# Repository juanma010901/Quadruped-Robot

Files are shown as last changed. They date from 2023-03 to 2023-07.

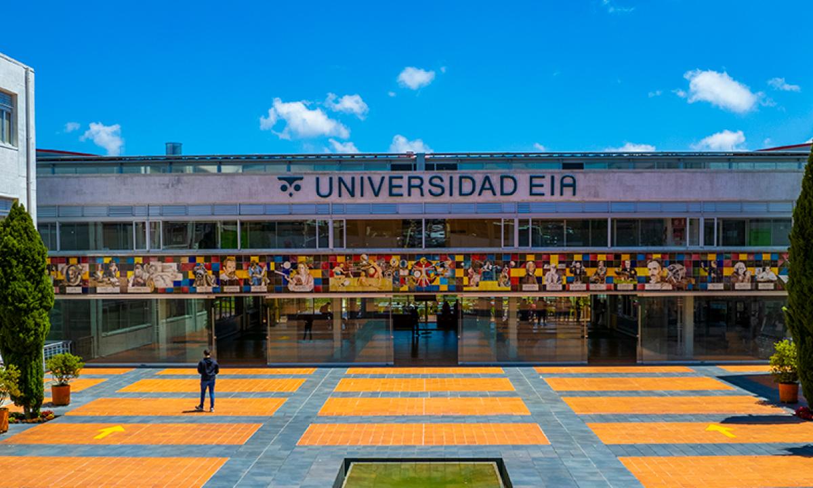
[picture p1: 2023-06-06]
Plataforma Web/FrontEnd/src/assets/UniversidadEIA_entrada.jpeg

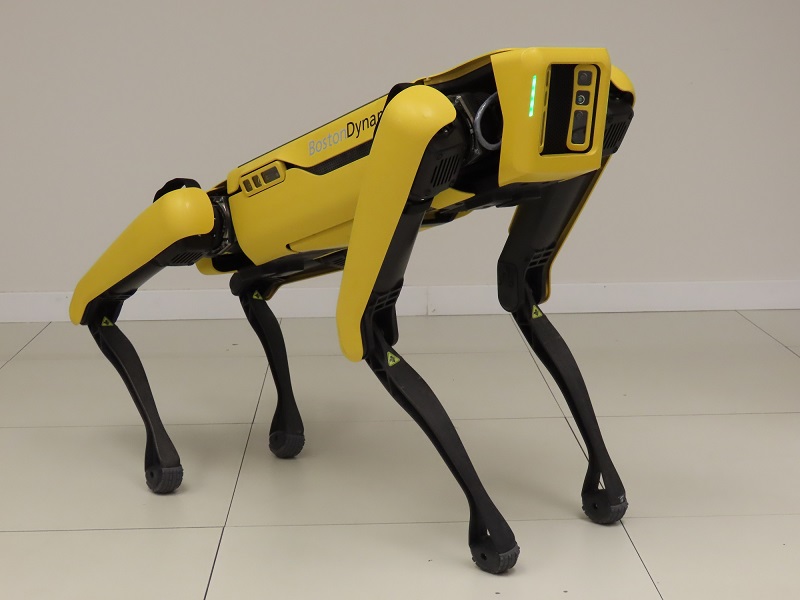
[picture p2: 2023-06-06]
Plataforma Web/FrontEnd/src/assets/robot_boston_dynamics.jpg

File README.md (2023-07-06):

<h1 align="center">
  <p>Diseño e implementación de un robot cuadrúpedo para la validación de estrategias de control en entornos peligrosos 🦾</p>
</h1>

<h2 align="center">
  <a href="https://juanma010901.github.io/Quadruped-Robot/">
    Quadruped Robot
  </a>
  <!--![Watchers](https://img.shields.io/github/watchers/juanma010901/Quadruped-Robot.svg)
  ![Stars](https://img.shields.io/github/stars/juanma010901/Quadruped-Robot.svg)-->
</h2><br>

<h3 align="center">
  <strong>Desarrollar un robot cuadrúpedo para el trabajo en entornos peligrosos como plataforma de validación de estrategias de control.</strong><br>
</h3>

<p align="center">
  Quadruped Robot
<p/>

A continuación se adjunta la [bitácora](https://docs.google.com/document/d/16br_ky9jK_mnqHfYBe1mgxbT8HZGymYTXOIlTPQXyck/edit?usp=sharing) del proyecto en la cual se podrán evidenciar las actividades realizadas durante cada fecha y los resultados obtenidos en la medida que se desarrollaba el proyecto.

## Materiales  🦾🔨
- [ESP32](https://github.com/juanma010901/Quadruped-Robot/blob/main/DataSheets/ESP32.pdf)
- [HC-SR04](https://github.com/juanma010901/Quadruped-Robot/blob/main/DataSheets/HC-SR04.PDF) x 2
- [LM2596](https://github.com/juanma010901/Quadruped-Robot/blob/main/DataSheets/LM2596.pdf) x2
- [MG996R](https://github.com/juanma010901/Quadruped-Robot/blob/main/DataSheets/MG996R.pdf) x 8
- [PCA9685](https://github.com/juanma010901/Quadruped-Robot/blob/main/DataSheets/PCA9685.PDF)
- [LCD16x2](https://github.com/juanma010901/Quadruped-Robot/blob/main/DataSheets/LCD16x2.pdf)
- [I2C Module](https://github.com/juanma010901/Quadruped-Robot/blob/main/DataSheets/I2C-1602-LCD.pdf)
<!-- - [Arduino Nano]()  -->

## Contributors 💡 and Contact 📩
| Juan Manuel Hincapié | Luis Alejandro Pépez | David Rozo Osorio | Universidad EIA |
| :---: | :---: | :---: | :---: |
| <a href="https://github.com/juanma010901">Juan Manuel</a> |  <a href="https://github.com/luisfbcudj94">Luis Pérez</a> |<a href="david.rozo31@eia.edu.co">David Rozo</a>| <a href="https://www.linkedin.com/school/universidad-eia/?originalSubdomain=co">Universidad EIA</a>| 
|  |  |  |

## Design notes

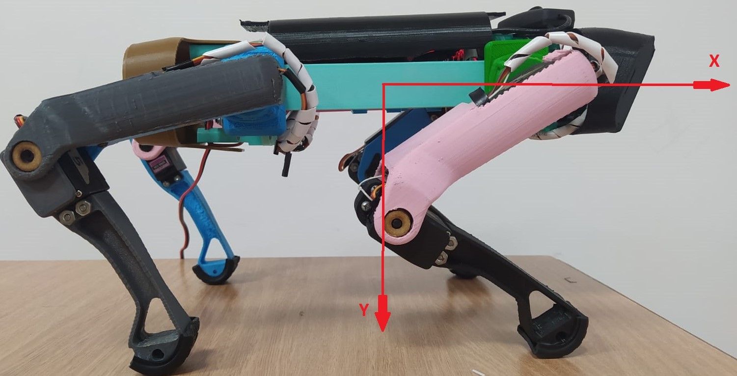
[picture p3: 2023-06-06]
Plataforma Web/FrontEnd/src/assets/EJES_ROBOT.jpeg

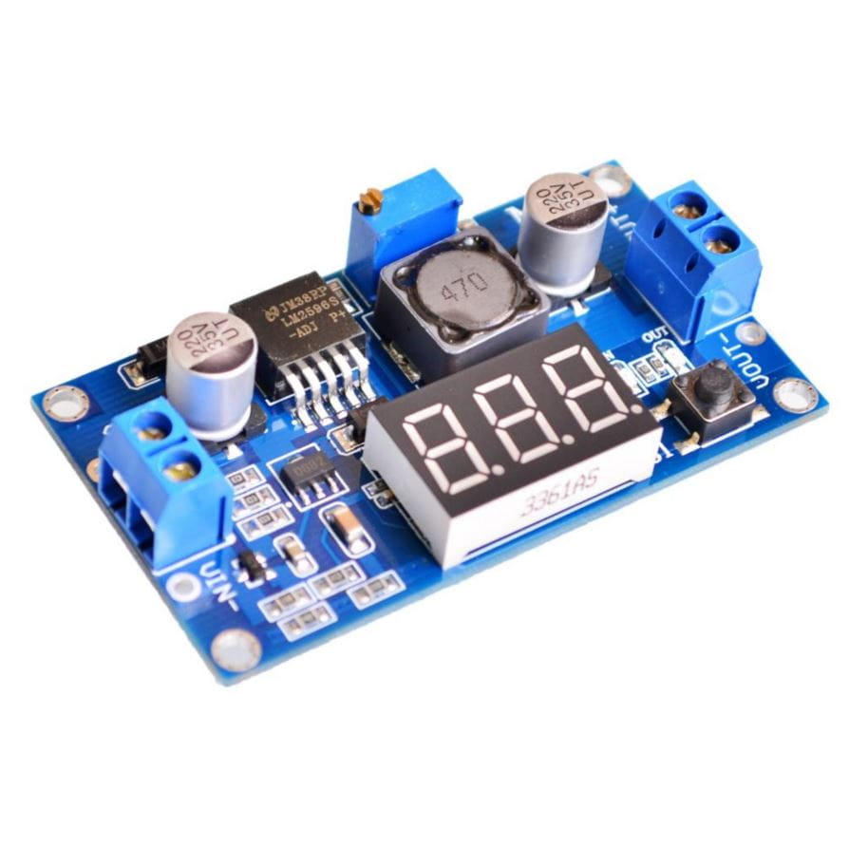
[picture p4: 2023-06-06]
DataSheets/LM2596-LED.jpg

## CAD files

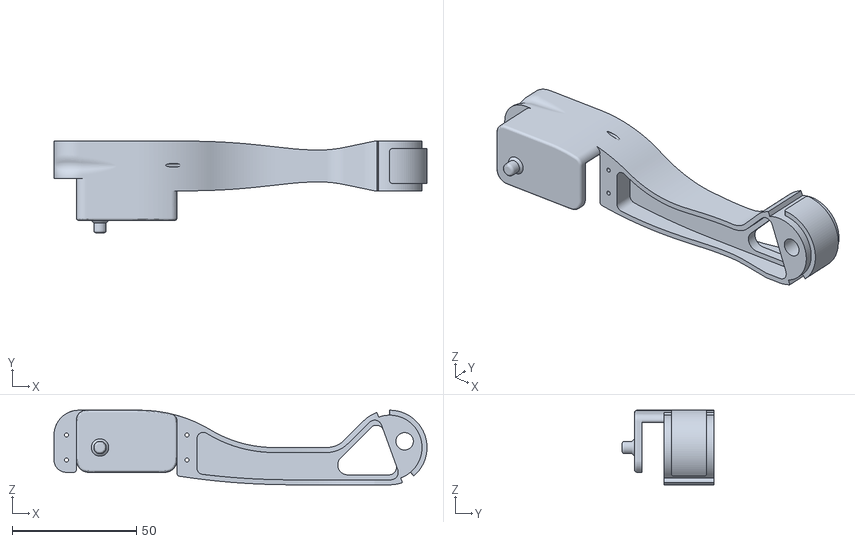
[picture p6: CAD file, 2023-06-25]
Diseños/files/V1.01_Left_Wrist.stl
150.0 x 36.9 x 30.0

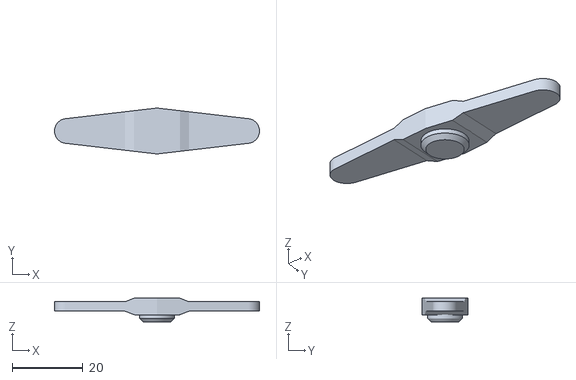
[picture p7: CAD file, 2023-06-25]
Diseños/files/ServoHorn_.stl
58.0 x 13.0 x 6.70

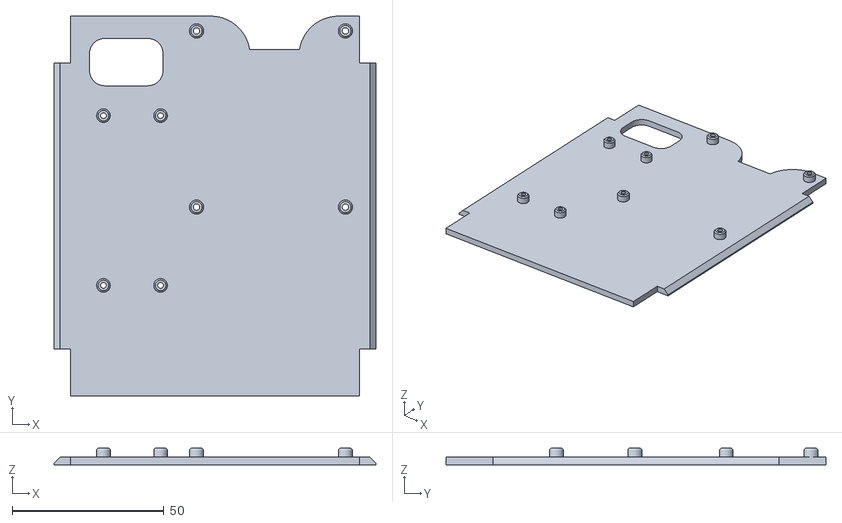
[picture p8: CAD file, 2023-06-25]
Diseños/files/V1.00_Chassis_PlateRPi.stl
106.0 x 125.0 x 5.44

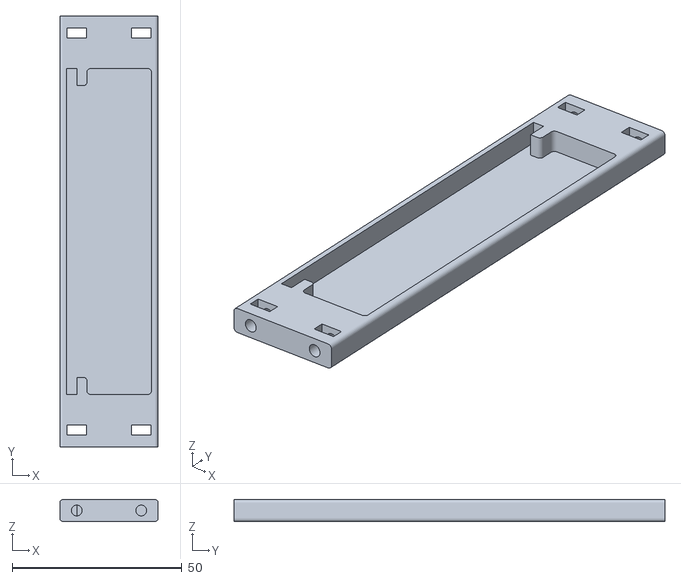
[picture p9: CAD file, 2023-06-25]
Diseños/files/V1.00_Chassis_Right.stl
29.0 x 127.0 x 6.50

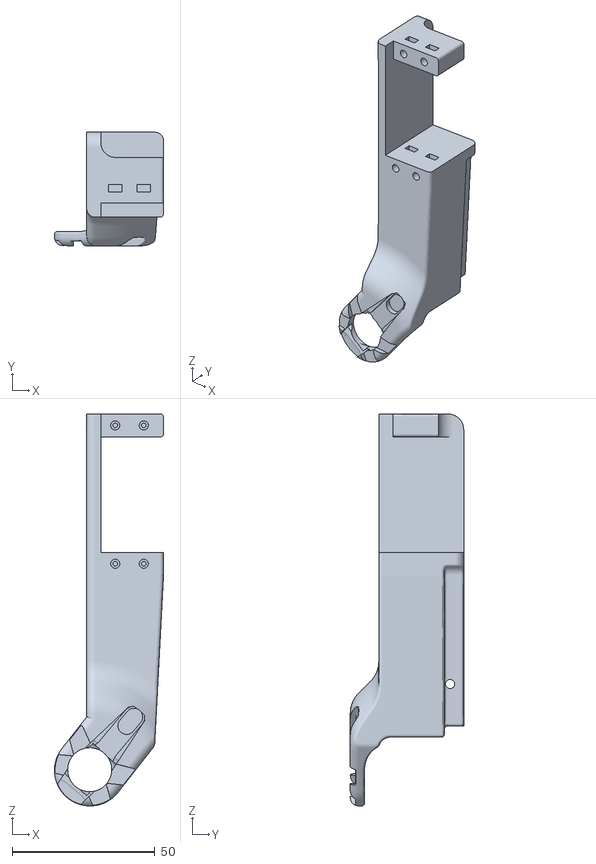
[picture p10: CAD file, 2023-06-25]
Diseños/files/V1.01_Right_MidArm.stl
38.3 x 39.8 x 137.4

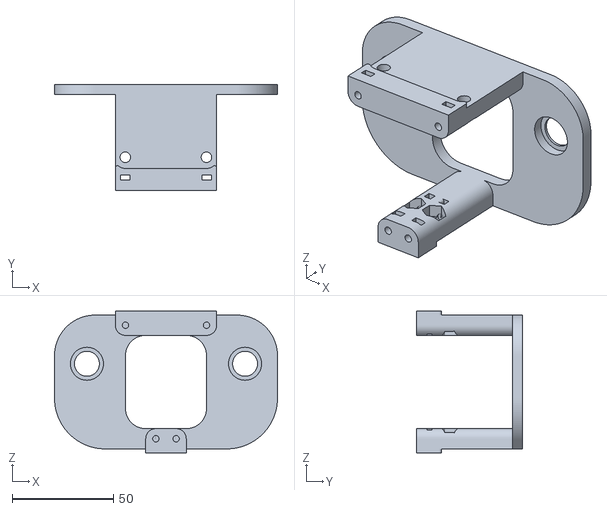
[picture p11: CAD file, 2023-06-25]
Diseños/files/V1.01_Rear_Shoulder_Outer.stl
110.0 x 52.5 x 70.0

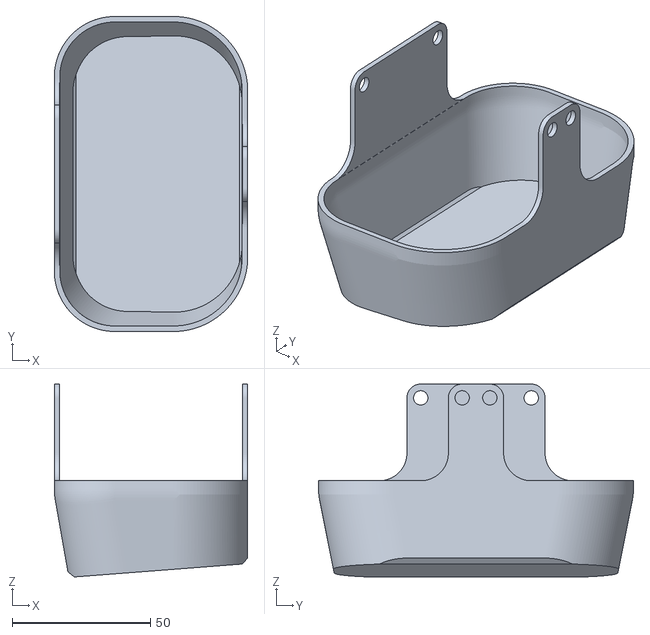
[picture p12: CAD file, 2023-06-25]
Diseños/files/V1.00_Body_Cover_Rearblank.stl
70.0 x 114.0 x 69.8

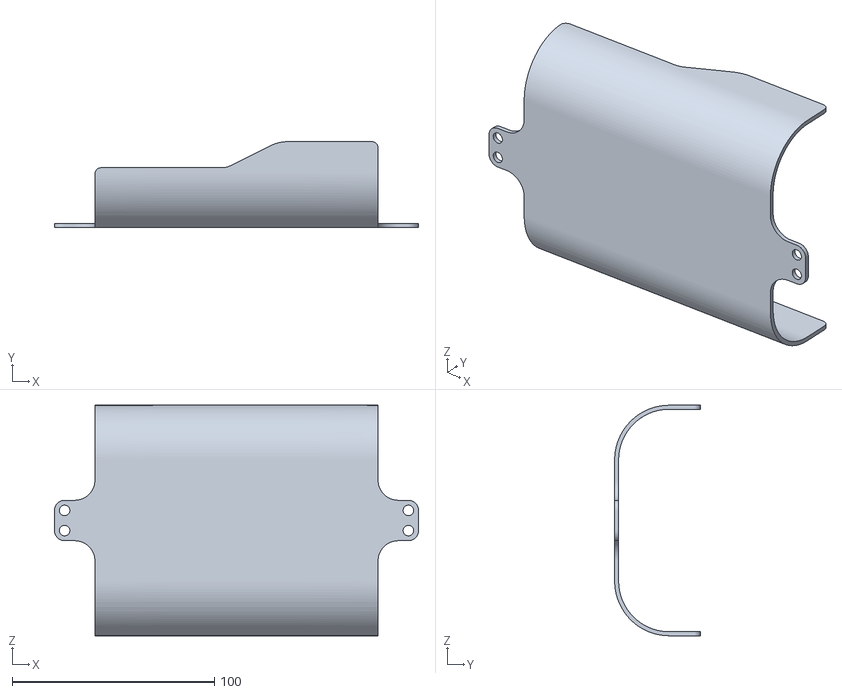
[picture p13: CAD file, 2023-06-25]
Diseños/files/V1.00_Body_Cover_Bottom.stl
180.0 x 42.4 x 114.0

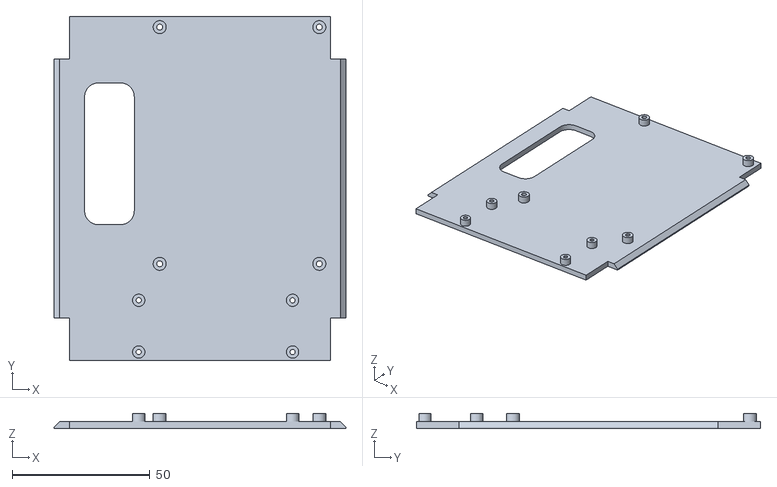
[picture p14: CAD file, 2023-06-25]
Diseños/files/V1.00_Chassis_PlateJetsonNano.stl
106.0 x 125.0 x 5.50

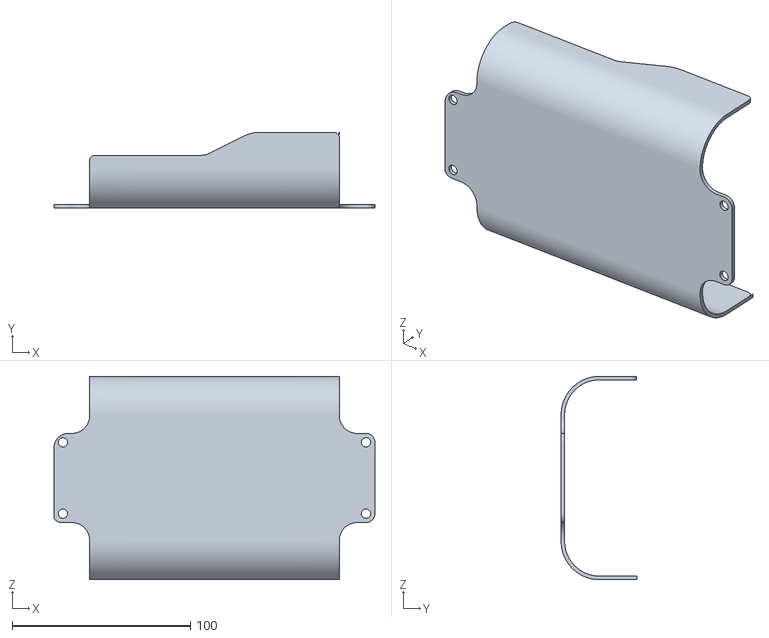
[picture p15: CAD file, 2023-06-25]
Diseños/files/V1.00_Body_Cover_Top.stl
180.0 x 42.5 x 114.0

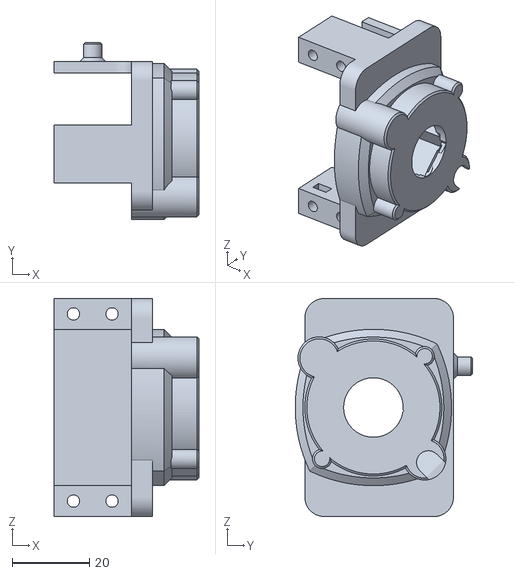
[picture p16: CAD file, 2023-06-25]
Diseños/files/V1.01_Left_UpperArm.stl
37.5 x 46.0 x 56.5

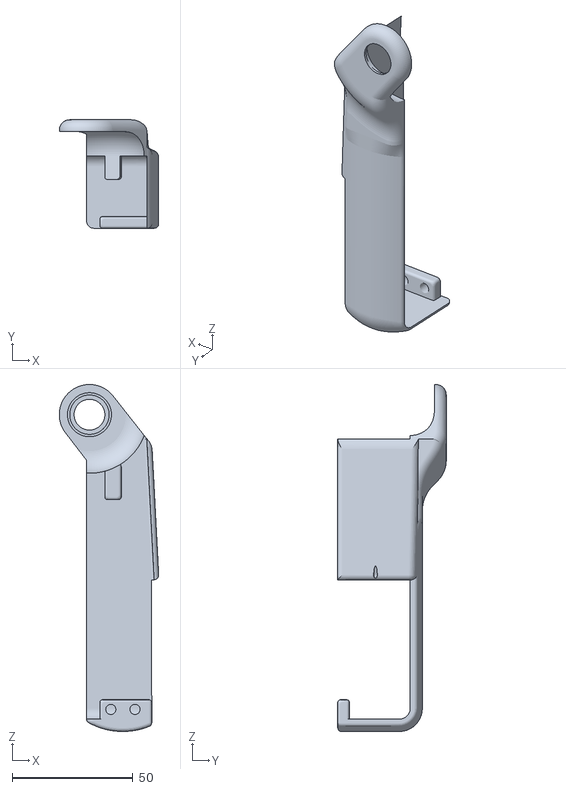
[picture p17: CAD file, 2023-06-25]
Diseños/files/V1.01_Left_MidArm_Cover.stl
41.1 x 44.9 x 143.6

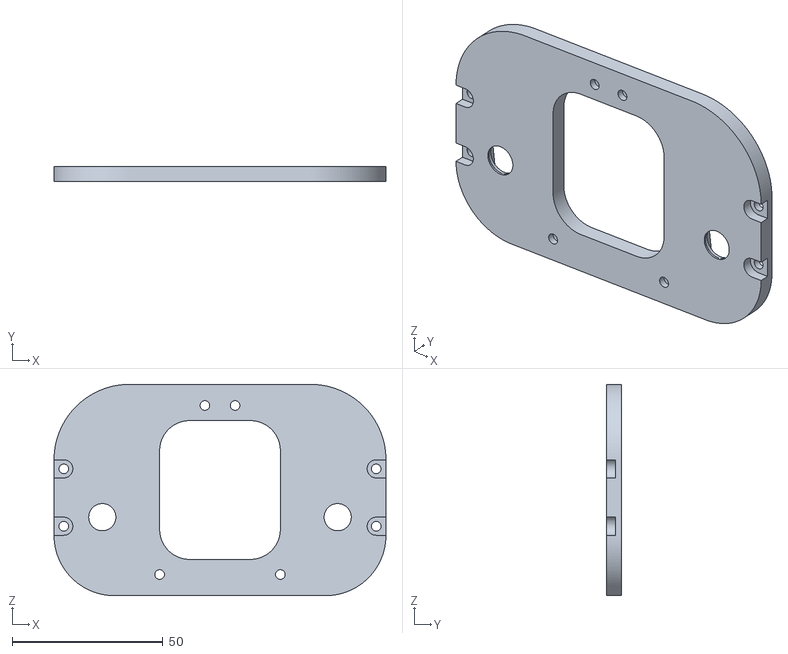
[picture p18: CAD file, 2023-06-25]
Diseños/files/V1.01_Rear_Shoulder_Inner.stl
110.0 x 5.00 x 70.0

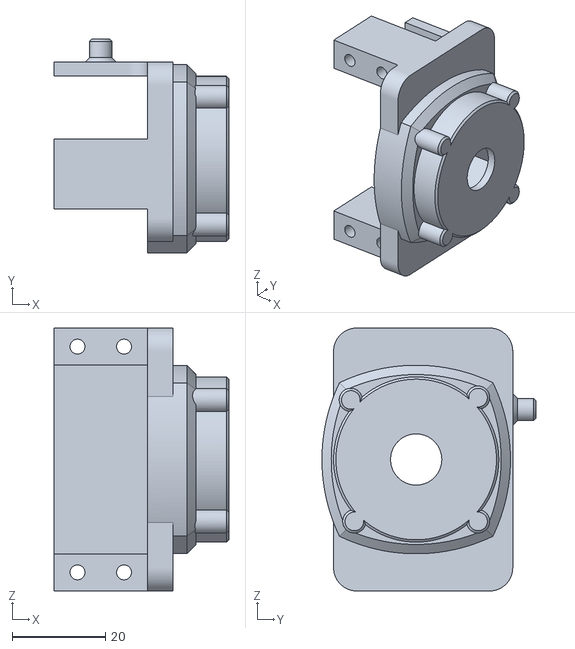
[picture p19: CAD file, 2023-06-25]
Diseños/files/UpperArm.stl
37.5 x 46.0 x 56.5

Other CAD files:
Diseños/files/WristForearm.stl
Diseños/files/V1.01_Right_Wrist.stl
Diseños/files/MidArm.stl
Diseños/files/V1.01_Right_MidArm_Cover.stl
Diseños/files/F_cover.stl
Diseños/files/Midarm_Cover.stl
Diseños/files/Outer_Shoulder.stl
Diseños/files/Rear_Cover.stl
Diseños/files/V1.00_Chassis_Left.stl
Diseños/files/V1.00_Foot.stl
Diseños/files/V1.00_Nose.stl
Diseños/files/V1.01_Front_Shoulder_Inner.stl
Diseños/files/V1.01_Front_Shoulder_Outer.stl
Diseños/files/V1.01_Left_MidArm.stl
Diseños/files/V1.01_Right_UpperArm.stl

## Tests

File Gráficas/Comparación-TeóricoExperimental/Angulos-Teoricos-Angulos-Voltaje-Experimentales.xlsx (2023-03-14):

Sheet: Hoja1
Voltaje M1 | Voltaje M2 | Puntos | Grados Teoricos M1 | Grados Teoriocos M2 | Grados linealizados M1 | Grados Linealizados M2
2.62066 | 0.851801 | 1 | 145.827 | 105.151 | 151.398 | 111.297
2.47645 | 0.37469 | 2 | 136.596 | 134.488 | 141.395 | 144.391
2.02189 | 1.06536 | 3 | 108.335 | 91.0852 | 109.865 | 96.484
2.61744 | 0.906587 | 4 | 145.827 | 105.151 | 151.175 | 107.497

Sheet: Hoja2
PUNTO | X | Y | VOLTAJE M1 | VOLTAJE M2 | PUNTO | GRADOS TEORICOS M1 | GRADOS TEORICOS M2 | GRADOS LINEALIZADOS M1 | GRADOS LINEALIZADOS M2 | GRADOS LINEALIZADOS CON AJUSTE M1 | GRADOS LINEALIZADOS CON AJUSTE M2 | DIFERENCIA TEORICOS - LINEALIZADOS | DIFERENCIA TEORICO - LINEALIZADOS AJUSTADOS
1 |  |  | 2.06218 | 1.38929 | 1 | 112.143 | 64.8972 | 112.66 | 69.0148 | 107.66 | 64.0148 | 0.461018521 | 3.997574525
2 |  |  | 2.82777 | 1.49246 | 2 | 157.909 | 59.2453 | 165.764 | 61.858 | 160.764 | 56.858 | 4.974383981 | 1.808003344
3 |  |  | 2.45061 | 0.985543 | 3 | 134.858 | 91.7365 | 139.603 | 97.0201 | 134.603 | 92.0201 | 3.518515772 | 0.1890877812
4 |  |  | 2.73592 | 1.37317 | 4 | 152.814 | 66.5638 | 159.393 | 70.1324 | 154.393 | 65.1324 | 4.305233814 | 1.033282291
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

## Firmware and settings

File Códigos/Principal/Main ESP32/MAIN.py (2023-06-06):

#print("Hello World!")
import adafruit_hcsr04
import adafruit_pca9685
import adafruit_minimqtt.adafruit_minimqtt as MQTT
import adafruit_requests as requests
import analogio
import board
import busio
import digitalio
import ipaddress
import json
import math
import pulseio
import wifi_networks
import socketpool
import ssl
import time
import wifi
from adafruit_motor import servo

#---------------------------------------------------------------------------------

#EndPoints API
getPuntos = "https://tg-backend-jl.azurewebsites.net/api/GetPuntos"
getModo = "https://tg-backend-jl.azurewebsites.net/api/GetModoActual"
updateModo = "https://tg-backend-jl.azurewebsites.net/api/ActualizarModo"

#getPuntos = "https://masterusers.azurewebsites.net/api/GetPuntos"
#getModo = "https://masterusers.azurewebsites.net/api/GetModoActual"
#updateModo = "https://masterusers.azurewebsites.net/api/ActualizarModo"


def connection():
    print("INICIO")
    wifi_networks.connect()
    print("FIN")
connection()

pool = socketpool.SocketPool(wifi.radio)
https = requests.Session(pool, ssl.create_default_context())

#---------------------------------------------------------------------------------

# Configura los LEDs
ledHome = digitalio.DigitalInOut(board.D5)
ledHome.direction = digitalio.Direction.OUTPUT
ledMarchas = digitalio.DigitalInOut(board.D18)
ledMarchas.direction = digitalio.Direction.OUTPUT
ledManiobras = digitalio.DigitalInOut(board.D19)
ledManiobras.direction = digitalio.Direction.OUTPUT
ledManual = digitalio.DigitalInOut(board.D23)
ledManual.direction = digitalio.Direction.OUTPUT

#--------------------------------------------------------------------------------
#Configuración de los ultrasonidos

# Configurar los pines Trig y Echo del sensor de ultrasonido
echo_pin1 = board.D34
echo_pin2 = board.D35
trig_pin1 = board.D32
trig_pin2 = board.D33

# Configurar el temporizador para medir la duración del pulso de eco
timer1 = pulseio.PulseIn(echo_pin1, maxlen=1)
timer2 = pulseio.PulseIn(echo_pin2, maxlen=1)

# Configurar el objeto del sensor de ultrasonido
sonar1 = adafruit_hcsr04.HCSR04(trigger_pin=trig_pin1, echo_pin=echo_pin1, timeout=0.1)
sonar2 = adafruit_hcsr04.HCSR04(trigger_pin=trig_pin2, echo_pin=echo_pin2, timeout=0.1)

#---------------------------------------------------------------------------------

#Suma
def puntosP1():
    x = [6, 9, 3]
    y = [11, 12, 13]
    return ([x, y])

def puntosP2():
    x = [0, 3, -3]
    y = [12, 14, 14]
    return ([x, y])

#Resta
def puntosP3():
    x = [0, -3, 3]
    y = [12, 14, 14]
    return ([x, y])

def puntosP4():
    x = [-3, -6, 0]
    y = [11, 12, 13]
    return ([x, y])

def puntosHome():
    puntosP1 = [3, 13]
    puntosP2 = [-3, 14]
    puntosP3 = [3, 14]
    puntosP4 = [0, 13]
    return([puntosP1, puntosP2, puntosP3, puntosP4])

def puntosAgachado():
    puntosP1 = [2, 9]
    puntosP2 = [-1, 9]
    puntosP3 = [1, 9]
    puntosP4 = [-1, 9]
    return([puntosP1, puntosP2, puntosP3, puntosP4])
    
def puntosParado():
    puntosP1 = [4, 20]
    puntosP2 = [-5, 21]
    puntosP3 = [5, 21]
    puntosP4 = [0, 20]
    return([puntosP1, puntosP2, puntosP3, puntosP4])

def puntosAdelante():
    puntosP1 = [6, 10]
    puntosP2 = [-1, 19]
    puntosP3 = [1, 19]
    puntosP4 = [-4, 10]
    return([puntosP1, puntosP2, puntosP3, puntosP4])

def puntosAtras():
    puntosP1 = [2, 17]
    puntosP2 = [-4, 11]
    puntosP3 = [4, 11]
    puntosP4 = [1, 17]
    return([puntosP1, puntosP2, puntosP3, puntosP4])

def puntosIzquierda():
    puntosP1 = [3, 11]
    puntosP2 = [-4, 11]
    puntosP3 = [4, 19]
    puntosP4 = [1, 19]
    return([puntosP1, puntosP2, puntosP3, puntosP4])

def puntosDerecha():
    puntosP1 = [3, 20]
    puntosP2 = [-3, 20]
    puntosP3 = [4, 12]
    puntosP4 = [-1, 12]
    return([puntosP1, puntosP2, puntosP3, puntosP4])

#---------------------------------------------------------------------------------

# Definición de pines I2C
SDA = board.D21
SCL = board.D22

# Configuración del bus I2C
i2c = busio.I2C(SCL, SDA)
pca = adafruit_pca9685.PCA9685(i2c, address=0x40)
pca.frequency = 50

# Configuración del Servomotor
servo_1 = servo.Servo(pca.channels[0], min_pulse=500, max_pulse=2500)
servo_2 = servo.Servo(pca.channels[2], min_pulse=500, max_pulse=2500)
servo_3 = servo.Servo(pca.channels[4], min_pulse=500, max_pulse=2500)
servo_4 = servo.Servo(pca.channels[6], min_pulse=500, max_pulse=2500)
servo_5 = servo.Servo(pca.channels[8], min_pulse=500, max_pulse=2500)
servo_6 = servo.Servo(pca.channels[10], min_pulse=500, max_pulse=2500)
servo_7 = servo.Servo(pca.channels[12], min_pulse=500, max_pulse=2500)
servo_8 = servo.Servo(pca.channels[14], min_pulse=500, max_pulse=2500)

# Definir las longitudes de las dos articulaciones del robot
l1 = 11
l2 = 13

#---------------------------------------------------------------------------------

# Funcion inversa izquierda
def inversaIzquierda(x, y):
    #print("Punto:" + str(x[i]) + "," + str(y[i]))
    #Calcular el valor de theta 2
    theta2 = math.acos((x**2 + y**2 - l1**2 - l2**2) / (2*l1*l2))

    # Calcular el valor de theta 1
    theta1 = math.atan2(y, x) + math.atan2(l2*math.sin(theta2), l1+l2*math.cos(theta2))
    
    #Angulos corregidos
    theta1c = math.degrees(theta1) - 90
    theta2c = 140 - math.degrees(theta2)

    return([theta1c,theta2c])

# Funcion inversa derecha
def inversaDerecha(x, y):
    #print("Punto:" + str(x[i]) + "," + str(y[i]))
    #Calcular el valor de theta 2
    theta2 = math.acos((x**2 + y**2 - l1**2 - l2**2) / (2*l1*l2))

    # Calcular el valor de theta 1
    theta1 = math.atan2(y, x) - math.atan2(l2*math.sin(theta2), l1+l2*math.cos(theta2))
    
    #Angulos corregidos
    theta1c = math.degrees(theta1)
    theta2c = math.degrees(theta2) + 40

    return([theta1c,theta2c])

#---------------------------------------------------------------------------------

# Mover Pata 1 (izquierda)
def calcularAngulosP1():
    
    # Invocar los puntos para mover las patas izquierdas
    puntos = puntosP1()
    x = puntos[0]
    y = puntos[1]

    angulosP1 = []

    for i in range(len(x)):
        angulosP1.append(inversaIzquierda(x[i],y[i]))
    return angulosP1

# Mover Pata 2 (izquierda)
def calcularAngulosP2():
    #Definir los vectores x e y
    puntos = puntosP2()
    x = puntos[0]
    y = puntos[1]

    angulosP2 = []

    for i in range(len(x)):
        angulosP2.append(inversaIzquierda(x[i],y[i]))
    return angulosP2
    
# Mover Pata 3 (derecha)
def calcularAngulosP3():
    #Definir los vectores x e y
    puntos = puntosP3()
    x = puntos[0]
    y = puntos[1]

    angulosP3 = []

    for i in range(len(x)):
        angulosP3.append(inversaDerecha(x[i],y[i]))
    return angulosP3

# Mover Pata 4 (derecha)
def calcularAngulosP4():
    puntos = puntosP4()
    x = puntos[0]
    y = puntos[1]

    angulosP4 = []

    for i in range(len(x)):
        angulosP4.append(inversaDerecha(x[i],y[i]))
    return angulosP4

#---------------------------------------------------------------------------------

#Funciones para mover las patas e imprimir la información
def moverP1(puntosP1):
    for i in range(len(puntosP1)):
            servo_1.angle = puntosP1[i][0]
            servo_2.angle = puntosP1[i][1]
            time.sleep(0.6)
            
def moverP2(puntosP2):
    for i in range(len(puntosP2)):
            servo_3.angle = puntosP2[i][0]
            servo_4.angle = puntosP2[i][1]
            time.sleep(0.6)
            
def moverP3(puntosP3):
    for i in range(len(puntosP3)):
            servo_5.angle = puntosP3[i][0]
            servo_6.angle = puntosP3[i][1]
            time.sleep(0.6)
            
def moverP4(puntosP4):
    for i in range(len(puntosP4)):
            servo_7.angle = puntosP4[i][0]
            servo_8.angle = puntosP4[i][1]
            time.sleep(0.6)

#---------------------------------------------------------------------------------
            
def moverP1P3(puntosP1, puntosP3):
    for i in range(len(puntosP1)):             
        servo_1.angle = puntosP1[i][0]
        servo_2.angle = puntosP1[i][1]
        servo_5.angle = puntosP3[i][0]
        servo_6.angle = puntosP3[i][1]
        time.sleep(0.3)
            
def moverP2P4(puntosP2, puntosP4):
    for i in range(len(puntosP2)):
            servo_3.angle = puntosP2[i][0]
            servo_4.angle = puntosP2[i][1]
            servo_7.angle = puntosP4[i][0]
            servo_8.angle = puntosP4[i][1]
            time.sleep(0.3)
      
#--------------------------------------------------------------------------------- 
            
def pararse():
    home = puntosHome()
    servo_3.angle, servo_4.angle = inversaIzquierda(home[1][0], home[1][1])
    servo_5.angle, servo_6.angle = inversaDerecha(home[2][0], home[2][1])
    time.sleep(0.3)
    servo_1.angle, servo_2.angle = inversaIzquierda(home[0][0], home[0][1])
    servo_7.angle, servo_8.angle = inversaDerecha(home[3][0], home[3][1])
    #time.sleep(0.1)
      
#--------------------------------------------------------------------------------- 
            
def home():
    home = puntosHome()
    servo_3.angle, servo_4.angle = inversaIzquierda(home[1][0], home[1][1])
    servo_5.angle, servo_6.angle = inversaDerecha(home[2][0], home[2][1])
    servo_1.angle, servo_2.angle = inversaIzquierda(home[0][0], home[0][1])
    servo_7.angle, servo_8.angle = inversaDerecha(home[3][0], home[3][1])
    #time.sleep(0.1)


#---------------------------------------------------------------------------------
            
#Marcha sencilla en la que se mueve un paso a la vez        
def marchaSencilla():
    moverP1(calcularAngulosP1())
    time.sleep(0.1)
    moverP3(calcularAngulosP3())
    time.sleep(0.1)
    moverP4(calcularAngulosP4())
    time.sleep(0.1)
    moverP2(calcularAngulosP2())
    time.sleep(0.1)

#---------------------------------------------------------------------------------

#Marcha de dos patas a la vez
def marchaDoble():
    moverP1P3(calcularAngulosP1(), calcularAngulosP3())
    time.sleep(0.1)
    moverP2P4(calcularAngulosP2(), calcularAngulosP4())
    time.sleep(0.1)
    
#--------------------------------------------------------------------------------- 
            
def maniobraAgachado():
    agachado = puntosAgachado()
    servo_1.angle, servo_2.angle = inversaIzquierda(agachado[0][0], agachado[0][1])
    servo_3.angle, servo_4.angle = inversaIzquierda(agachado[1][0], agachado[1][1])
    servo_5.angle, servo_6.angle = inversaDerecha(agachado[2][0], agachado[2][1])
    servo_7.angle, servo_8.angle = inversaDerecha(agachado[3][0], agachado[3][1])
    #time.sleep(0.1)
    
#--------------------------------------------------------------------------------- 
    
def maniobraParado():
#     if(estadoAnterior == "Home"):
#         espera = 0.2
#     elif(estadoAnterior == "Maniobra agachado"):
#         espera = 0.35
# #     elif(estadoAnterior == "Agachado hacia atras"):
# #         servo_1.angle, servo_2.angle = inversaIzquierda(home[0][0], home[0][1])
# #         servo_7.angle, servo_8.angle = inversaDerecha(home[3][0], home[3][1])
#     else:
#         espera = 0.2
#         
    parado = puntosParado()
    servo_3.angle, servo_4.angle = inversaIzquierda(parado[1][0], parado[1][1])
    servo_5.angle, servo_6.angle = inversaDerecha(parado[2][0], parado[2][1])
    time.sleep(0.35)
    servo_1.angle, servo_2.angle = inversaIzquierda(parado[0][0], parado[0][1])
    servo_7.angle, servo_8.angle = inversaDerecha(parado[3][0], parado[3][1])
    #time.sleep(0.1)
    
#---------------------------------------------------------------------------------   

def maniobraInclinadoIzquierda():
    izquierda = puntosIzquierda()
    servo_1.angle, servo_2.angle = inversaIzquierda(izquierda[0][0], izquierda[0][1])
    servo_3.angle, servo_4.angle = inversaIzquierda(izquierda[1][0], izquierda[1][1])
    servo_5.angle, servo_6.angle = inversaDerecha(izquierda[2][0], izquierda[2][1])
    servo_7.angle, servo_8.angle = inversaDerecha(izquierda[3][0], izquierda[3][1])
    #time.sleep(0.1)
    
#---------------------------------------------------------------------------------   

def maniobraInclinadoDerecha():
    derecha = puntosDerecha()
    servo_1.angle, servo_2.angle = inversaIzquierda(derecha[0][0], derecha[0][1])
    servo_3.angle, servo_4.angle = inversaIzquierda(derecha[1][0], derecha[1][1])
    servo_5.angle, servo_6.angle = inversaDerecha(derecha[2][0], derecha[2][1])
    servo_7.angle, servo_8.angle = inversaDerecha(derecha[3][0], derecha[3][1])
    #time.sleep(0.1)

#--------------------------------------------------------------------------------- 
    
def maniobraInclinadoAdelante():
    adelante = puntosAdelante()
    servo_1.angle, servo_2.angle = inversaIzquierda(adelante[0][0], adelante[0][1])
    servo_3.angle, servo_4.angle = inversaIzquierda(adelante[1][0], adelante[1][1])
    servo_5.angle, servo_6.angle = inversaDerecha(adelante[2][0], adelante[2][1])
    servo_7.angle, servo_8.angle = inversaDerecha(adelante[3][0], adelante[3][1])
    #time.sleep(0.1)
    
#--------------------------------------------------------------------------------- 
    
def maniobraInclinadoAtras():
    atras = puntosAtras()
    servo_1.angle, servo_2.angle = inversaIzquierda(atras[0][0], atras[0][1])
    servo_3.angle, servo_4.angle = inversaIzquierda(atras[1][0], atras[1][1])
    servo_5.angle, servo_6.angle = inversaDerecha(atras[2][0], atras[2][1])
    servo_7.angle, servo_8.angle = inversaDerecha(atras[3][0], atras[3][1])
    #time.sleep(0.1)
    
#--------------------------------------------------------------------------------- 
   
def puntosManual():
    #print("Fetching text from %s" % getPuntos)
    response = https.get(getPuntos)
    puntos = response.json()
    response.close()
    print(puntos)
    print(type(puntos))
    
    #Pedir puntos de home para comparar en caso de que el enviado sea el Home
    home = puntosHome()
    x3h = home[2][0]
    x4h = home[3][0]
    print(x3h, x4h)
    
    try:
        
        x1 = puntos[0]["p1X"]
        y1 = puntos[0]["p1Y"]
        x2 = puntos[0]["p2X"]
        y2 = puntos[0]["p2Y"]
        x3 = puntos[0]["p3X"]
        y3 = puntos[0]["p3Y"]
        x4 = puntos[0]["p4X"]
        y4 = puntos[0]["p4Y"]
    
        servo_1.angle, servo_2.angle = inversaIzquierda(x1, y1)
        servo_3.angle, servo_4.angle = inversaIzquierda(x2, y2)
        if x3h == x3:
            servo_5.angle, servo_6.angle = inversaDerecha(x3, y3)
        else:
            servo_5.angle, servo_6.angle = inversaDerecha(-x3, y3)
        if x4h == x4:
            servo_7.angle, servo_8.angle = inversaDerecha(x4, y4)
        else:
            servo_7.angle, servo_8.angle = inversaDerecha(-x4, y4)
    except:
        print("Punto fuera de rango")
    
#---------------------------------------------------------------------------------  
    
# Definir la función de medición de distancia
def medir_distancia(sensor):
    try:
        if sensor == 1:
            distance1 = sonar1.distance
            return distance1
        elif sensor == 2:
            distance2 = sonar2.distance
            return distance2
    except:
        if sensor == 1:
            distance1 = 450
            return distance1
        elif sensor == 2:
            distance2 = 450
            return distance2

#--------------------------------------------------------------------------------- 
    
#Actualizar modo
def cambioHome():
    data = '{"Id":1,"Activo": true,"Descripcion": "Home","SeccionId": 1}\n'
    print("POSTing data to {0}: {1}".format(updateModo, data))
    response = https.put(updateModo, data=data)
    
#---------------------------------------------------------------------------------
    
    
#---------------------------------------------------------------------------------
#CICLO INFINITO
#--------------------------------------------------------------------------------- 
    
pararse()

json = {}

#estadoAnterior = ""
while True:
    
    try:
        print("Fetching text from %s" % getModo)
        response = https.get(getModo)
        info = response.json()
        response.close()
        print(info)
        estado = info["descripcion"]
        #print(type(json))
        #print(estado)
    except Exception as e:
        print("Error de conexion: ", e)
        estado = "Home"
        connection()
    
    if (estado == "Home"):
        ledHome.value = True
        home()
        time.sleep(1)
        ledHome.value = False
    elif (estado == "Maniobra agachado"):
        ledManiobras.value = True
        maniobraAgachado()
        time.sleep(1)
        ledManiobras.value = False
    elif (estado == "Maniobra parado"):
        ledManiobras.value = True
        maniobraParado()
        time.sleep(1)
        ledManiobras.value = False
    elif (estado == "Maniobra inclinado hacia adelante"):
        ledManiobras.value = True
        maniobraInclinadoAdelante()
        time.sleep(1)
        ledManiobras.value = False
    elif (estado == "Maniobra inclinado hacia atras"):
        ledManiobras.value = True
        maniobraInclinadoAtras()
        time.sleep(1)
        ledManiobras.value = False
    elif (estado == "Equilibrio dos patas izquierda"):
        ledManiobras.value = True
        maniobraInclinadoIzquierda()
        time.sleep(1)
        ledManiobras.value = False
    elif (estado == "Equilibrio dos patas derecha"):
        ledManiobras.value = True
        maniobraInclinadoDerecha()
        time.sleep(1)
        ledManiobras.value = False
    elif (estado == "Ingreso manual de puntos"):
        ledManual.value = True
        puntosManual()
        time.sleep(1)
        ledManual.value = False
    elif (estado == "Marcha doble"):
        ledMarchas.value = True
        distance1 = medir_distancia(1)
        distance2 = medir_distancia(2)
        print(distance1, distance2)
        home()
        if distance1 < 25.0 or distance2 < 25.0:
            cambioHome()
        else:
            marchaDoble()
        ledMarchas.value = False
    elif (estado == "Marcha sencilla"):
        ledMarchas.value = True
        distance1 = medir_distancia(1)
        distance2 = medir_distancia(2)
        print(distance1, distance2)
        home()
        if distance1 < 25.0 or distance2 < 25.0:
            cambioHome()
        else:
            marchaSencilla()
        ledMarchas.value = False

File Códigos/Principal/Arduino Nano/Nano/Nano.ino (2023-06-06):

#include <ArduinoJson.h>
#include <Wire.h>
#include <LiquidCrystal_I2C.h> 

LiquidCrystal_I2C lcd(0x27,16,2);

byte QR[8] = {
  B00000,
  B00000,
  B11111,
  B11111,
  B01001,
  B10010,
  B01001,
  B00000
};

byte EIA[8] = {
  B11111,
  B01110,
  B00100,
  B11011,
  B11011,
  B00100,
  B00100,
  B00000
};

int N1 = A0;
int N2 = A1;
int N3 = A2;
int N4 = A3;
int N5 = A6;
int N6 = A7;

int M1 = 0;
int M3 = 0;
int M5 = 0;
int M7 = 0;
int M2 = 0;
int M4 = 0;

void setup() {
  lcd.init();
  lcd.backlight();
  lcd.clear();
  lcd.setCursor(0, 0);
  lcd.print("UNIVERSIDAD EIA");
  lcd.setCursor(0, 1);
  lcd.print("QUADRUPED ROBOT");

  // Crear el carácter personalizado en la posición 1 (índice 0)
  lcd.createChar(1, QR);
  lcd.createChar(2, EIA);
  lcd.setCursor(15, 0);
  lcd.write(byte(2));
  lcd.setCursor(15, 1);
  lcd.write(byte(1));

  pinMode(N1, INPUT);
  pinMode(N2, INPUT);
  pinMode(N3, INPUT);
  pinMode(N4, INPUT);
  pinMode(N5, INPUT);
  pinMode(N6, INPUT);

  Serial.begin(9600);
}

void loop() {
  lcd.display();

  M1 = analogRead(N1);
  M3 = analogRead(N2);
  M5 = analogRead(N3);
  M7 = analogRead(N4);
  M2 = analogRead(N5);
  M4 = analogRead(N6);

  // Crear el documento JSON
  DynamicJsonDocument doc(128);

  // Agregar datos al JSON
  doc["A11"] = M1;
  doc["A21"] = M3;
  doc["A31"] = M5;
  doc["A41"] = M7;
  doc["A12"] = M2;
  doc["A22"] = M4;

  // Serializar el JSON en un búfer
  char buffer[128];
  serializeJson(doc, buffer);

  // Enviar el JSON a través del puerto serial
  Serial.println(buffer);

  delay(500);
}

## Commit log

2023-03-13 Creation of GitHub repo for quadruped robot
    [0-45.csv, 135-180.csv, 135-90.csv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]
2023-03-14 Organization of test code folders
    [Angulos-Teoricos-Angulos-Voltaje-Experimentales.xlsx]
2023-03-15 PWM correct test
2023-03-15 PWM duty cycle corrections
    [puntos_inversa-izquierda.py]
2023-03-15 Add puntos inversa for left side in ESP32
2023-03-15 Correction of duty cycle of PWM
    [puntos_inversa-derecho.py]
2023-03-17 Corrections of first version of basic gait (L1,L3,L4,L2)
    [prueba_full.py]
2023-03-21 Corrections to adapt the codes to the PCA9685
    [inversa-izquierda-PCA.py, prueba_full.py]
2023-03-21 Corrections to move motor from raspberry pi pico
    [mover_motor.py]
2023-03-21 First test about remote control (led control) from adafruit IO
2023-03-23 New configuration of left legs
2023-03-27 New corrections for the actual assembly
    [second-complete-test.py]
2023-03-29 Test of HTTPS requests to send information about the position of each motor
2023-04-19 Calibration of points for the gaits and movements
2023-04-24 Calibration of the predefined points
2023-04-26 Ultrasound sensors function added
2023-05-22 Arduino file
2023-05-29 New arduino files with ADC
    [Linealización-Motores.xlsx]
2023-05-29 New aux ESP32 file
2023-06-05 Main code error handling fix
    [AUXI.py, LCD.ino, MAIN.py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]
2023-06-25 Diseños CAD
    [F_cover.stl, MidArm.stl, Midarm_Cover.stl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]
